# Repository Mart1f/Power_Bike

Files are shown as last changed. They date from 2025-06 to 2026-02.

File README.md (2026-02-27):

# 🚴‍♂️ Power Bike – Energy-Generating Bicycle System

This repository contains the complete source code and system description for an **interactive energy-generating bicycle** that monitors, transmits, and visualizes real-time electrical parameters such as **RPM, voltage, current, and power output**.

---

## 🔧 System Overview

The project integrates multiple hardware components, including:

- 🧠 **Raspberry Pi 4** – acts as the main display unit
- 📡 **Two ESP32 microcontrollers** – for sensor reading and control logic
- ⚙️ **Dynamo** – generates electricity as the user pedals
- 💡 **120V LED strips** – visually indicate energy production via relays

---

## 🔁 How It Works

1. As the user **pedals**, the **dynamo** generates electricity.
2. A dedicated **ESP32**:
   - Reads raw sensor data (RPM, voltage, current).
   - Scales and processes the values.
   - Sends the data via **Bluetooth** to the **Raspberry Pi 4**.
   - Simultaneously **broadcasts** the power data over **Wi-Fi** (MAC-based protocol) to a second ESP32.
3. The **Raspberry Pi 4**:
   - Receives the data via Bluetooth.
   - Displays real-time metrics on a connected screen using a **Python GUI (Tkinter)** dashboard.
4. The **second ESP32**:
   - Receives power data over Wi-Fi.
   - Controls **relay modules** to turn on/off high-voltage **LED strips**.
   - The number of LEDs turned on increases with the pedaling effort and power output.

---

## 📊 Features

- Real-time data visualization:
  - 🔵 **Voltage**
  - 🟢 **Current**
  - 🔁 **RPM**
  - 🔌 **Power (W)**
- Bluetooth communication for dashboard data
- Wi-Fi-based broadcast to auxiliary control system
- LED feedback system representing physical effort
- Modular and scalable architecture
- Educational and interactive energy awareness system

---

## 📸 Screenshots

- Interactive Dashboard
  
WhatsApp Image 2025-07-02 at 12 19 26 PM (1)

- PCB Send Data



- PCB Control and Signal Conditioning



---

## 📦 Requirements

- Python 3.x
- `tkinter` for GUI (pre-installed on Raspberry Pi OS)
- Serial libraries for ESP32 code (e.g., Arduino framework)
- Bluetooth configuration (for Raspberry Pi)
- Relay modules compatible with 120V LED strips

---

## 👨‍💻 Author

**Martín Felipe Bermúdez Romero**  
Student of Electronic Engineering  
Universidad Distrital Francisco José de Caldas  
martimrome13@gmail.com*
mfbermudezr@udistrital.edu.co*

---

## 🚀 Future Improvements (optional)

- Data logging to CSV or database
- Web dashboard for remote monitoring
- Energy storage monitoring (e.g., batteries or capacitors)
- Support for multiple bikes or users

---

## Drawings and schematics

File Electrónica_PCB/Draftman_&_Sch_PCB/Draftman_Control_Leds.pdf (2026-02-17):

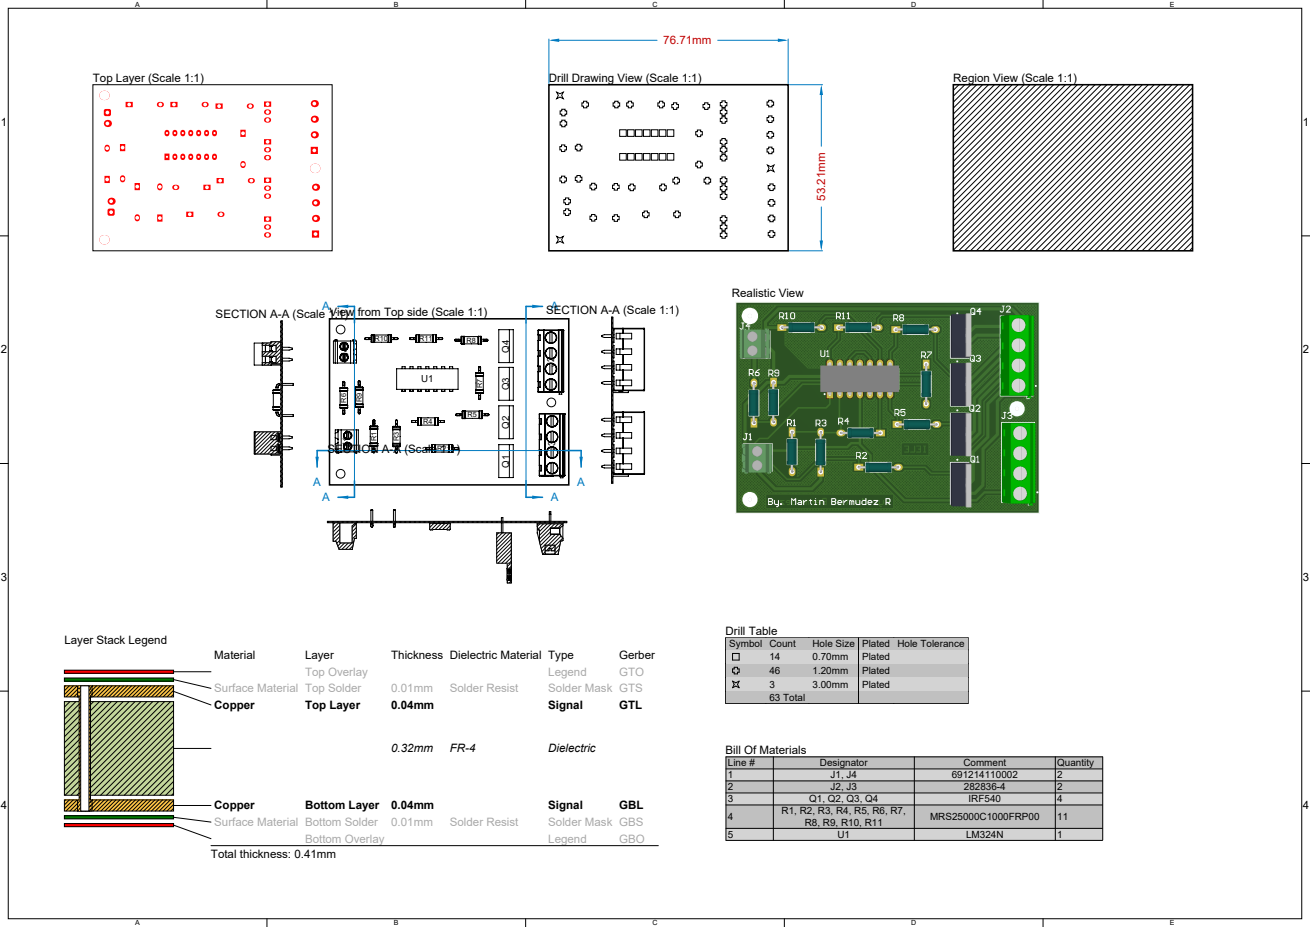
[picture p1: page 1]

View from Top side (Scale 1:1)

Symbol | Count | Hole Size | Plated | Hole Tolerance

14 | 0.70mm | Plated
46 | 1.20mm | Plated
3 | 3.00mm | Plated
63 Total

Line # | Designator | Comment | Quantity
1 | J1, J4 | 691214110002 | 2
2 | J2, J3 | 282836-4 | 2
3 | Q1, Q2, Q3, Q4 | IRF540 | 4
4 | R1, R2, R3, R4, R5, R6, R7, R8, R9, R10, R11 | MRS25000C1000FRP00 | 11

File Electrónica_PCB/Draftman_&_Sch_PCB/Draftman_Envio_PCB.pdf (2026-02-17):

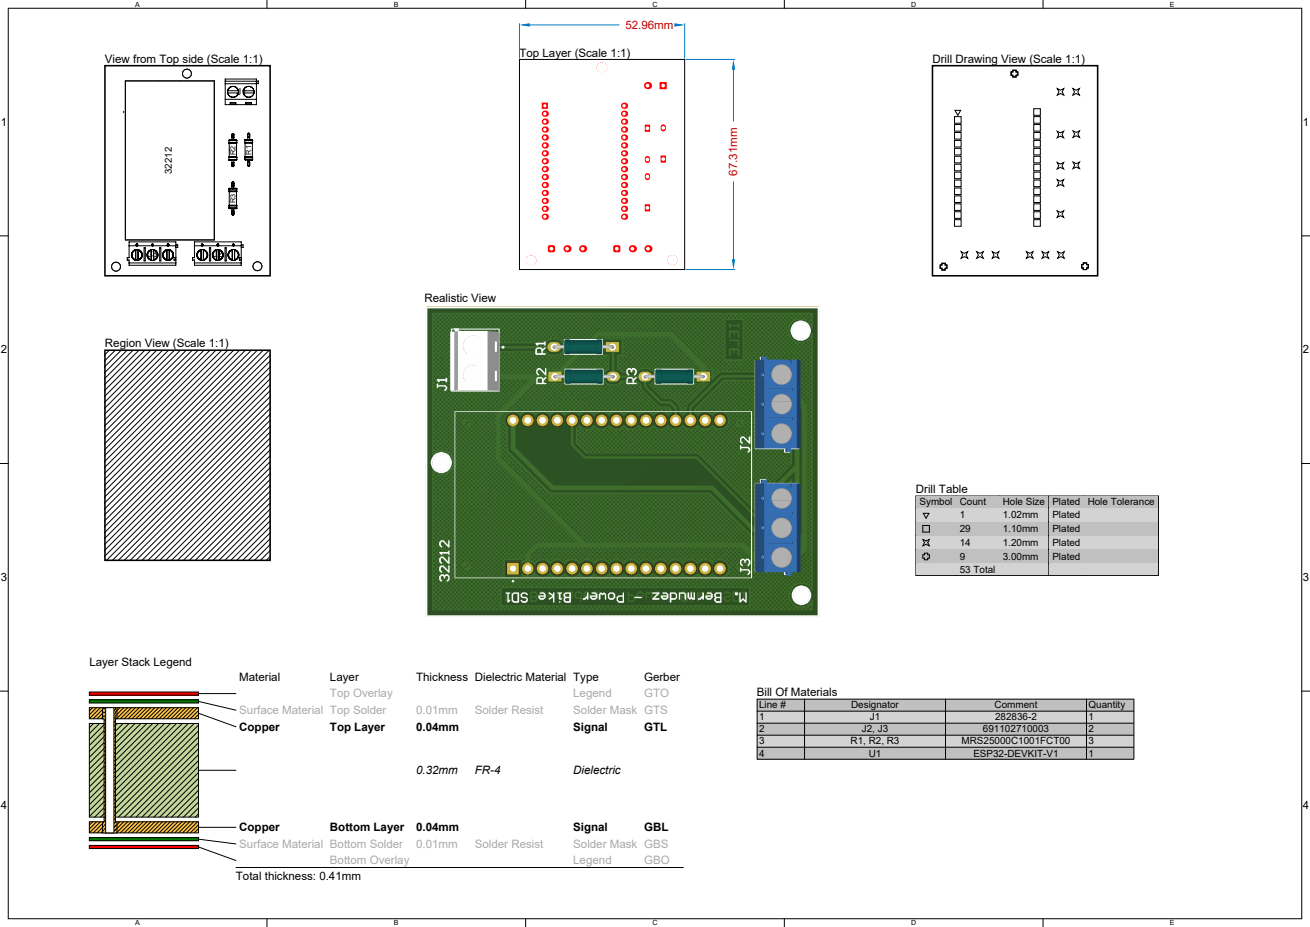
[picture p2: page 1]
4 ³²²¹²; Material; Layer; Thickness Dielectric Material Type; Gerber; Top Overlay; Legend; GTO; Surface Material Top Solder; Solder Resist; Solder Mask GTS; Copper; Top Layer; Signal; GTL; Dielectric; Bottom Layer 0.04mm; GBL; Surface Material Bottom Solder 0.01mm; Solder Mask GBS; Bottom Overlay; GBO; Total thickness: 0.41mm; Realistic View; Drill Table

Top Layer (Scale 1:1)

View from Top side (Scale 1:1)

Drill Drawing View (Scale 1:1)

Region View (Scale 1:1)

Symbol | Count | Hole Size | Plated | Hole Tolerance

1 | 1.02mm | Plated
29 | 1.10mm | Plated
14 | 1.20mm | Plated
9 | 3.00mm | Plated
53 Total

Layer Stack Legend

Bill Of Materials

Line # | Designator | Comment | Quantity
1 | J1 | 282836-2 | 1
2 | J2, J3 | 691102710003 | 2
3 | R1, R2, R3 | MRS25000C1001FCT00 | 3
4 | U1 | ESP32-DEVKIT-V1 | 1

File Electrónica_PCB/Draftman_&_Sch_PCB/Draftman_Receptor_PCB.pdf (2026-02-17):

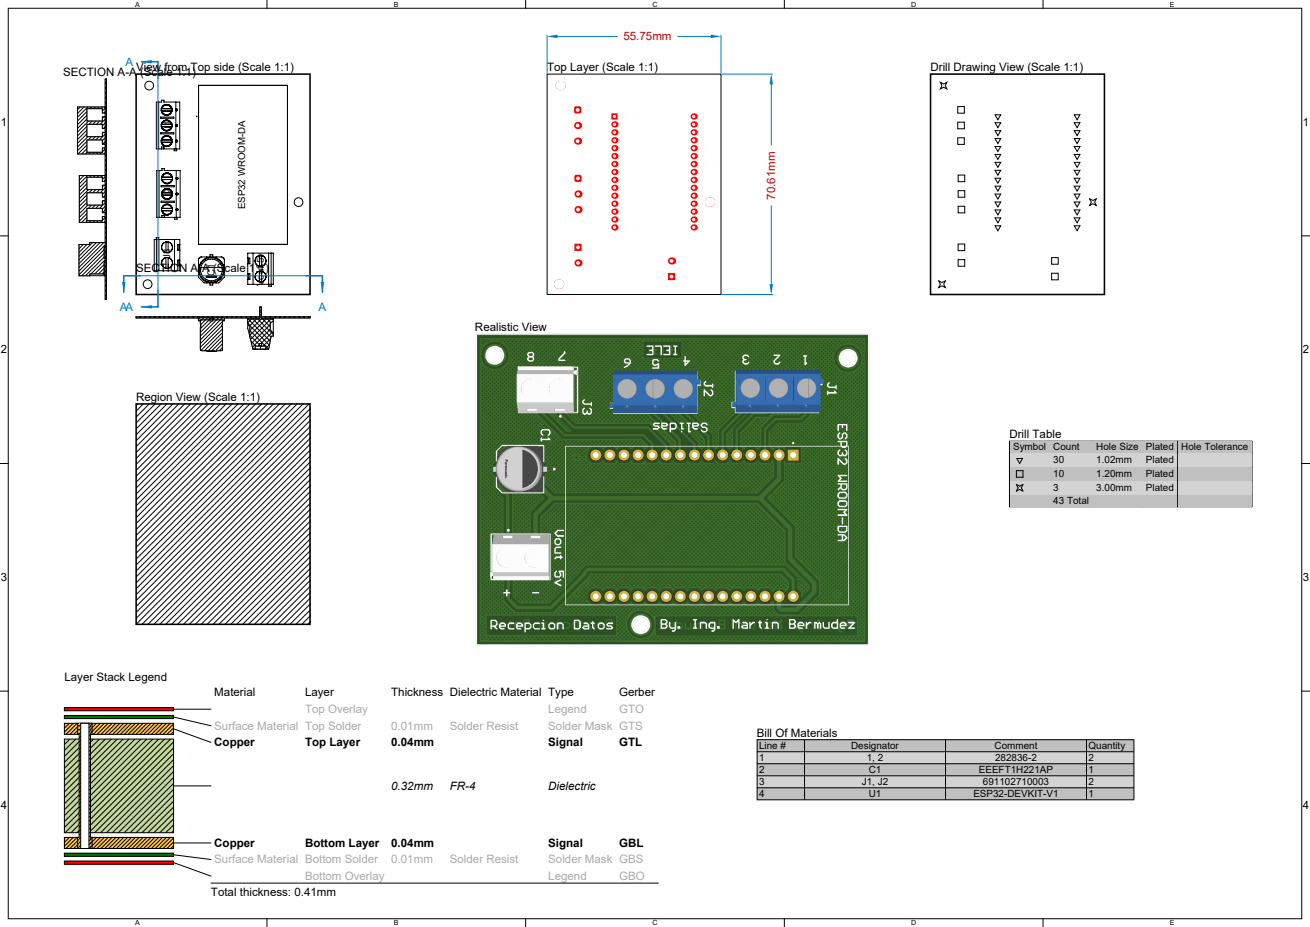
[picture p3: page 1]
4 ESP³² WROOM⁻DA C¹ J2 J1 J3; Vout 5v; View from Top side (Scale 1:1); Top Layer (Scale 1:1); Drill Drawing View (Scale 1:1); SECTION A-A (Scale 1:1); Realistic View; Material; Layer; Thickness Dielectric Material Type; Gerber; Top Overlay; Legend; GTO; Surface Material Top Solder; Solder Resist; Solder Mask GTS; Copper; Top Layer; Signal; GTL; Dielectric; Bottom Layer 0.04mm; GBL; Surface Material Bottom Solder 0.01mm; Solder Mask GBS; Bottom Overlay; GBO; Total thickness: 0.41mm; Drill Table

Region View (Scale 1:1)

Symbol | Count | Hole Size | Plated | Hole Tolerance

30 | 1.02mm | Plated
10 | 1.20mm | Plated
3 | 3.00mm | Plated
43 Total

Layer Stack Legend

Bill Of Materials

Line # | Designator | Comment | Quantity
1 | 1, 2 | 282836-2 | 2
2 | C1 | EEEFT1H221AP | 1
3 | J1, J2 | 691102710003 | 2
4 | U1 | ESP32-DEVKIT-V1 | 1

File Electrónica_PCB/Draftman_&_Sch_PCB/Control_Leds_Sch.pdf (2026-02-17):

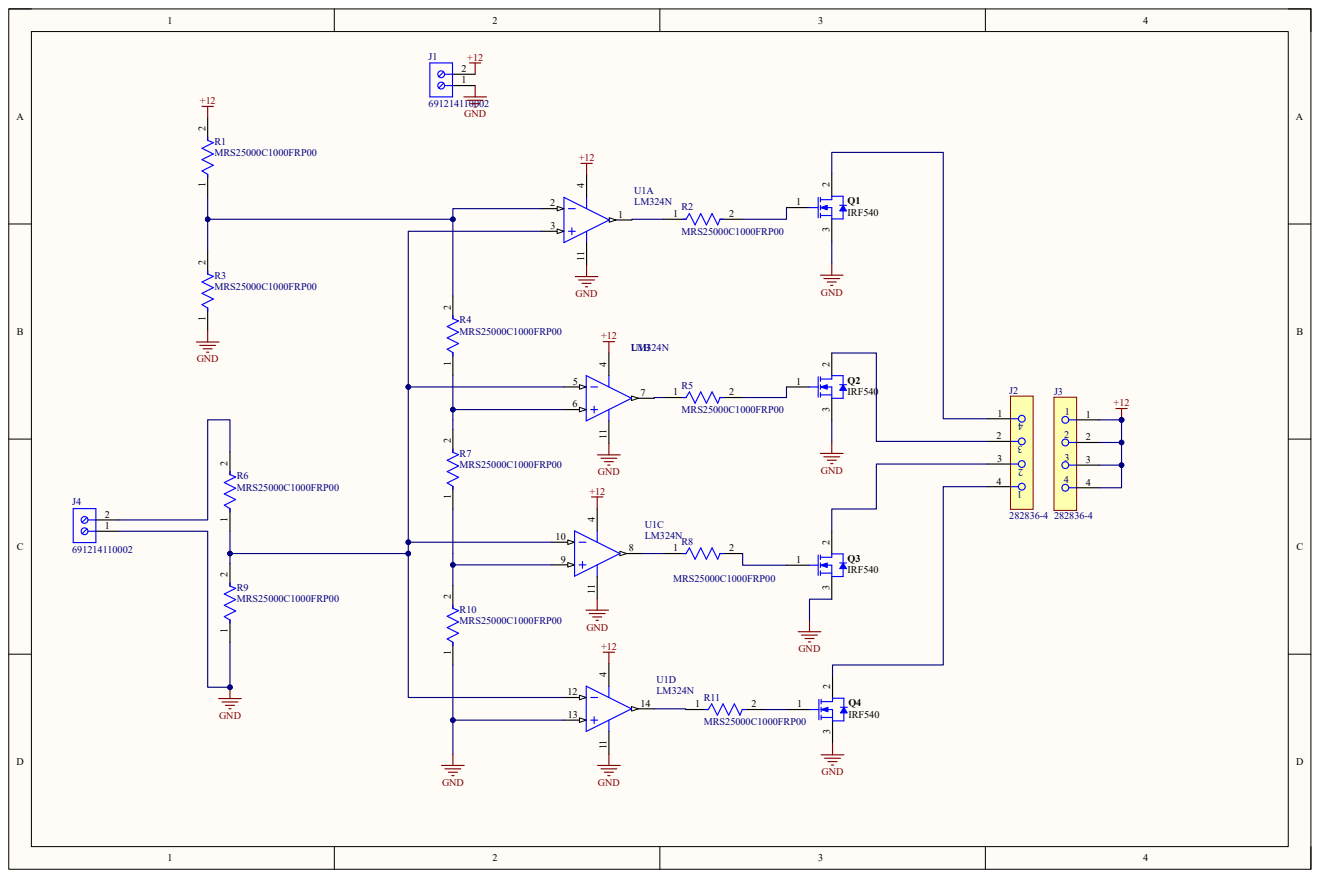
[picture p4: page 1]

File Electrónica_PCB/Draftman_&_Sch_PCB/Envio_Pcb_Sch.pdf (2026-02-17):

# MRS25000C1001FCT00 12

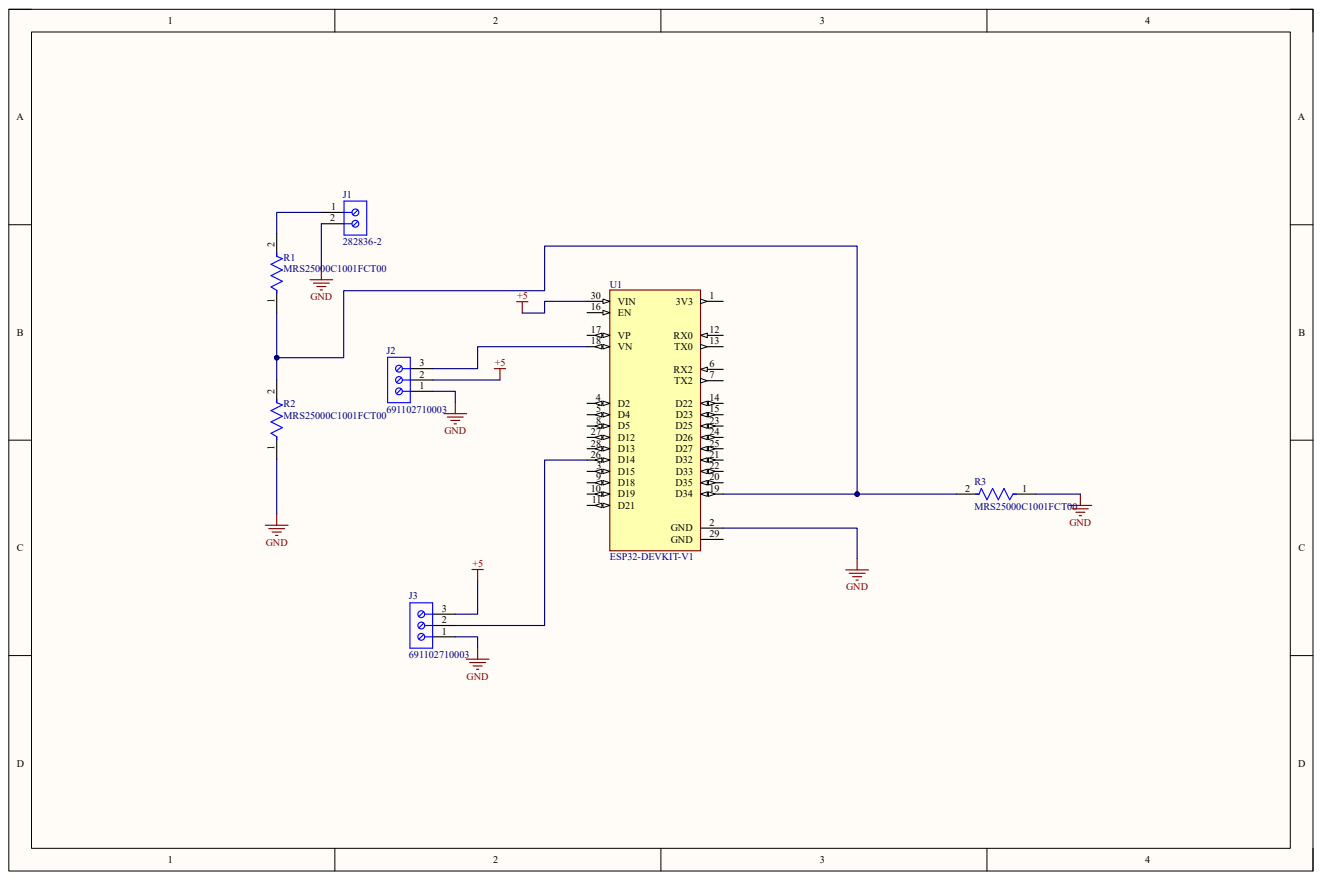
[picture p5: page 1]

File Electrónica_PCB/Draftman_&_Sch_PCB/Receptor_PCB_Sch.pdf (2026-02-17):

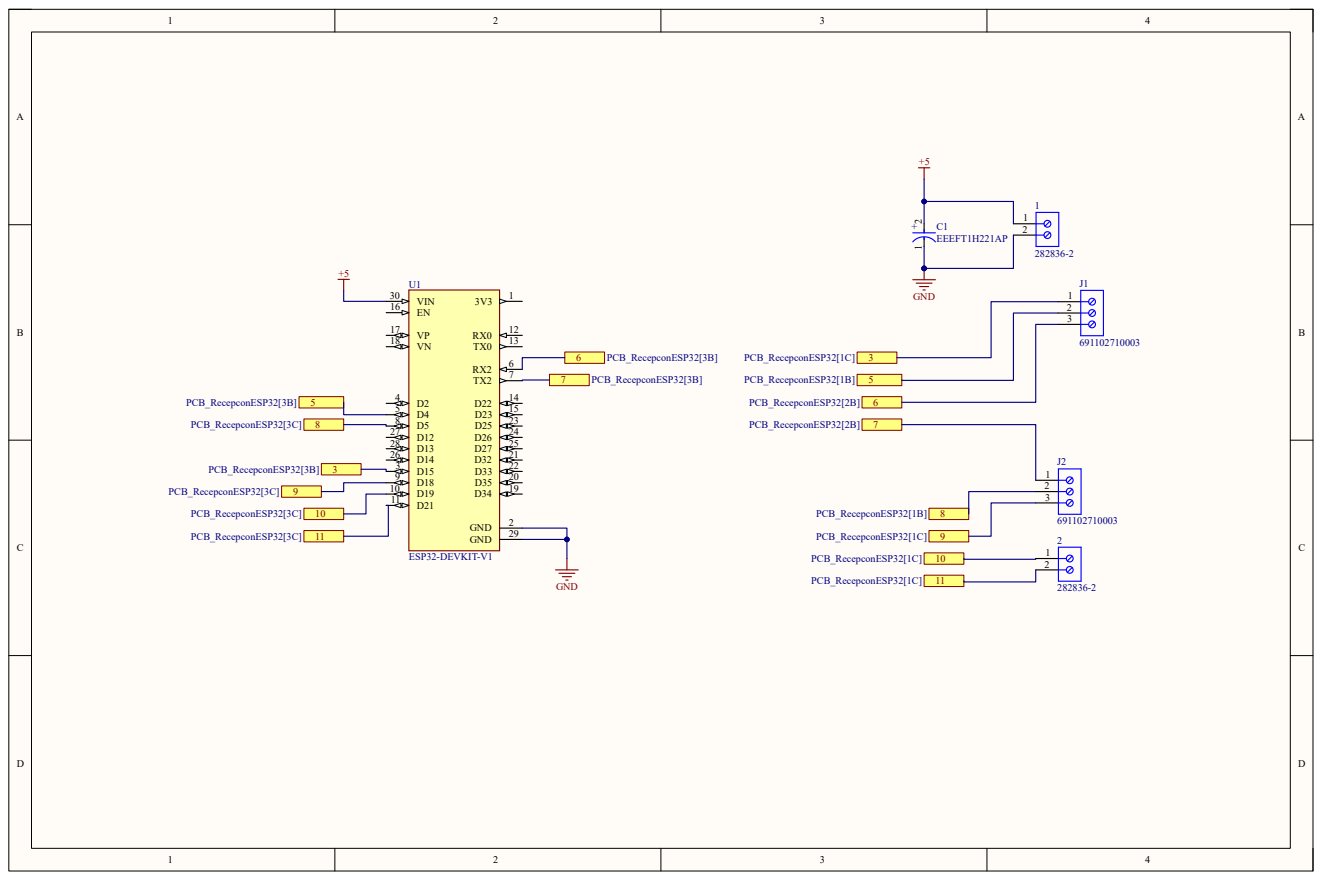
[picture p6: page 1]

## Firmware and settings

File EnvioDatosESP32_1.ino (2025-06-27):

#include <BluetoothSerial.h>

#include <esp_now.h>
#include <WiFi.h>

BluetoothSerial SerialBT;

// Dirección MAC de broadcast (para todos los ESP32 receptores)
uint8_t broadcastAddress[] = {0xFF, 0xFF, 0xFF, 0xFF, 0xFF, 0xFF};

typedef struct struct_message {
  float voltaje;
  float corriente;
  float rpm;
} struct_message;

struct_message myData;

// Pines
const int pinVoltaje = 34;
const int pinCorriente = 39;
const int pinSensorHall = 14;

// Variables RPM
volatile int conteoPulsos = 0;
unsigned long tiempoAnterior = 0;
unsigned long tiempoUltimoPulso = 0;
unsigned long tiempoEntrePulsos = 0;

void contarPulsos() {
  unsigned long ahora = millis();
  tiempoEntrePulsos = ahora - tiempoUltimoPulso;
  tiempoUltimoPulso = ahora;
  conteoPulsos++;
}

void OnSent(const uint8_t *mac_addr, esp_now_send_status_t status) {
  Serial.print("ESP-NOW ");
  Serial.println(status == ESP_NOW_SEND_SUCCESS ? "OK" : "Fallo");
}

void setup() {
  Serial.begin(115200);
  SerialBT.begin("ESP32_BT");  // Nombre del dispositivo Bluetooth
  pinMode(pinSensorHall, INPUT);
  attachInterrupt(digitalPinToInterrupt(pinSensorHall), contarPulsos, FALLING);

  // Inicializa WiFi en modo estación
  WiFi.mode(WIFI_STA);

  // Inicializa ESP-NOW
  if (esp_now_init() != ESP_OK) {
    Serial.println("Error iniciando ESP-NOW");
    return;
  }

  esp_now_register_send_cb(OnSent);

  esp_now_peer_info_t peerInfo = {};
  memcpy(peerInfo.peer_addr, broadcastAddress, 6);
  peerInfo.channel = 0;
  peerInfo.encrypt = false;

  if (esp_now_add_peer(&peerInfo) != ESP_OK) {
    Serial.println("Error agregando peer");
    return;
  }

  Serial.println("ESP32 lista para enviar por Bluetooth y ESP-NOW");
}

void loop() {
  // Lectura de sensores
  int analogValue = analogRead(pinVoltaje);
  float v_a = (analogValue * 3.3) / 4095.0;
  float v_adc = v_a + 0.2;
  //myData.voltaje = 15.81 * exp(4.5 * v_adc) - 38.7;
  myData.voltaje = (-21.565 * (v_adc*v_adc))+(91.939 * v_adc)-17.475;

  int lecturaCorriente = analogRead(pinCorriente);
float voltajeCorriente = (lecturaCorriente * 3.3) / 4095.0;
float corrienteCalculada = ((voltajeCorriente - 2.5) / 0.1) + 1.6;
myData.corriente = corrienteCalculada < 0 ? 0 : corrienteCalculada;

  //float rpm = 0;
  // unsigned long ahora = millis();

  // noInterrupts();
  // unsigned long tiempoLocal = tiempoEntrePulsos;
  // unsigned long ultimoPulso = tiempoUltimoPulso;
  // interrupts();

  // if (tiempoLocal > 0 && (ahora - ultimoPulso < 1500)) {
  //   rpm = 60000.0 / tiempoLocal;
  // }
  // myData.rpm = rpm;

  myData.rpm = myData.voltaje * (218.0 / 60.0);  // Aproximadamente rpm = voltaje × 3.633



  
  // Enviar por ESP-NOW broadcast
  esp_now_send(broadcastAddress, (uint8_t *)&myData, sizeof(myData));

  // Enviar por Bluetooth
  Serial.println(v_adc);
  SerialBT.print(myData.voltaje, 2);
  Serial.println(myData.voltaje, 2);
  SerialBT.print(",");
  SerialBT.print(myData.corriente, 2);
  SerialBT.print(",");
  SerialBT.println(myData.rpm, 1);

  Serial.println("Enviado por BT y ESP-NOW");

  delay(500);
}

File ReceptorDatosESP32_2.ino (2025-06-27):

#include <Arduino.h>
#include <esp_now.h>
#include <WiFi.h>
#include "esp_wifi.h"


#define NUM_SECTIONS 8

// Estructura de datos recibida
typedef struct struct_message {
  float voltage;
} struct_message;

struct_message incomingData;

// Pines conectados a los relés
const int relayPins[NUM_SECTIONS] = {15, 4, 16, 17, 5, 18, 19, 21};

void OnDataRecv(const uint8_t *mac, const uint8_t *incomingDataRaw, int len) {
  memcpy(&incomingData, incomingDataRaw, sizeof(incomingData));
  float v = incomingData.voltage;

  Serial.print("Voltaje recibido: ");
  Serial.println(v);


  for (int i = 0; i < NUM_SECTIONS; i++) {
    digitalWrite(relayPins[i], HIGH);
  }

  // Activar salidas de reles
  float step = 58.5 / NUM_SECTIONS;
  int numRelaysOn = v / step;

  for (int i = 0; i < numRelaysOn && i < NUM_SECTIONS; i++) {
    digitalWrite(relayPins[i], LOW);  // Encender rele
  }
}

void setup() {
  Serial.begin(19200);
  Serial.println("Iniciando ESP32...");

  WiFi.mode(WIFI_STA);
  esp_wifi_set_channel(0, WIFI_SECOND_CHAN_NONE);

  Serial.println("Modo WiFi STA activado.");

  // Configura pines de rele como salidas
  for (int i = 0; i < NUM_SECTIONS; i++) {
    pinMode(relayPins[i], OUTPUT);
    digitalWrite(relayPins[i], HIGH);  // Inicio lógico apagado
  }

  Serial.println("Relés configurados.");

  if (esp_now_init() != ESP_OK) {
    Serial.println("Error iniciando ESP-NOW");
    return;
  }

  Serial.println("ESP-NOW iniciado correctamente.");
  esp_now_register_recv_cb(OnDataRecv);

  Serial.println("ESP32 receptora lista.");
  Serial.print("MAC Address (para el emisor): ");
  Serial.println(WiFi.macAddress());
}

void loop(){
  
}

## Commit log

2025-06-27 README - Description Power Bike Project.md
2025-07-02 Create codigointerfazlinux
    Código utilizado para la Raspberry Pi4, entorno Linux, para realizar la visualización gráfica en tiempo real de los datos de Power Bike
2026-02-27 Add PCB Images
    Added additional images to the README for better visualization.
